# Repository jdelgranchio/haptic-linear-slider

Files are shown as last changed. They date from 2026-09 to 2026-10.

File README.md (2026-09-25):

# Haptic Linear Slider

A PCB for a motorized, haptic linear slider. An RP2354 (RP2350 with built-in flash) drives a
Bourns PSM01 motorized slide potentiometer through a DRV8876 H-bridge. The board also has a
14 V boost (TLV61048) for the motor supply, a buck converter (DIO54335), USB-C, and SWD over
Tag-Connect TC2030.

Made with **KiCad 10**.

## Layout

```
haptic-linear-slider.kicad_{pro,sch,pcb}
sym-lib-table, fp-lib-table       project library tables (paths use ${KIPRJMOD})
lib/
  _symbols/
    haptic-linear-slider.kicad_sym   project symbols, library nickname "_Symbols"
    MCU_RaspberryPi_RP2350.kicad_sym RP2350 symbol from Raspberry Pi's minimal design
  _footprints.pretty/                project footprints, library nickname "_Footprints"
  _3D/                               STEP models for project footprints
scripts/export.sh                    generates fab outputs and docs with kicad-cli
scripts/site.sh                      builds the GitHub Pages index from those outputs
.github/workflows/kicad.yml          CI: export, Pages (main), releases (v* tags)
```

Use the stock KiCad libraries for anything they already cover. Add a part to the project
libraries only when they don't have it.

## Adding a part from Mouser

1. Download the KiCad model from the Mouser product page (SamacSys / Library Loader).
2. In the Symbol Editor, copy the symbol into `_Symbols`. Rename it to
   `<short description> (<manufacturer>)`, e.g. `37V 3.5A H-Bridge (Texas Instruments)`.
3. Copy the `.kicad_mod` into `lib/_footprints.pretty/` and the `.stp` into `lib/_3D/`.
4. Set the footprint's 3D model to `${KIPRJMOD}/lib/_3D/<part>.stp`. Set the symbol's
   `Footprint` field to `_Footprints:<name>`.
5. Keep the `Manufacturer_Name`, `Manufacturer_Part_Number`, `Mouser Part Number` and
   `Mouser Price/Stock` fields. The BOM export reads them.

## Generating outputs

```sh
scripts/export.sh                 # writes everything to output/ (git-ignored)
STRICT_ERC=1 scripts/export.sh    # fail on ERC violations (STRICT_DRC=1, or STRICT=1 for both)
IBOM=path/to/generate_interactive_bom.py scripts/export.sh   # also build the interactive BOM
```

This produces:

- **checks**: ERC/DRC reports
- **fab**: Gerbers and drill files (plus a zip), a grouped BOM with part-number columns, a
  pick-and-place CSV
- **docs**: schematic PDF, PCB layers PDF, top/bottom assembly drawing PDFs, top/bottom 3D
  renders (PNG), a 3D STEP model
- **presentation**: board outline SVGs, bare and with part bodies, for slides and handbooks
- **datasheets**: a PDF per BOM part, from the `Datasheet` field. Some hosts (Mouser,
  Samsung, ST, …) block scripted downloads. Save those by hand as
  `lib/datasheets/<MPN>.pdf`; the CI run summary lists which ones are missing.

The Gerber layers come from the plot settings saved in the board file (PCB Editor → Plot).
Title blocks show `${REVISION}`: "dev" in the editor, the git tag or short SHA in exports.

## CI

- **Push to `main`**: builds everything, fails on ERC violations, and publishes the latest
  outputs to GitHub Pages. Only the newest deploy is kept. Per-commit workflow artifacts
  expire after 14 days.
- **Push a `v*` tag** (e.g. `v0.1`): also attaches all outputs to a GitHub release. Tag each
  revision you send to fab.

CI uses the `kicad/kicad:10.0-full` image (it includes the stock 3D models). DRC is report-only for now. Set `STRICT_DRC: 1` in the workflow once routing is done.

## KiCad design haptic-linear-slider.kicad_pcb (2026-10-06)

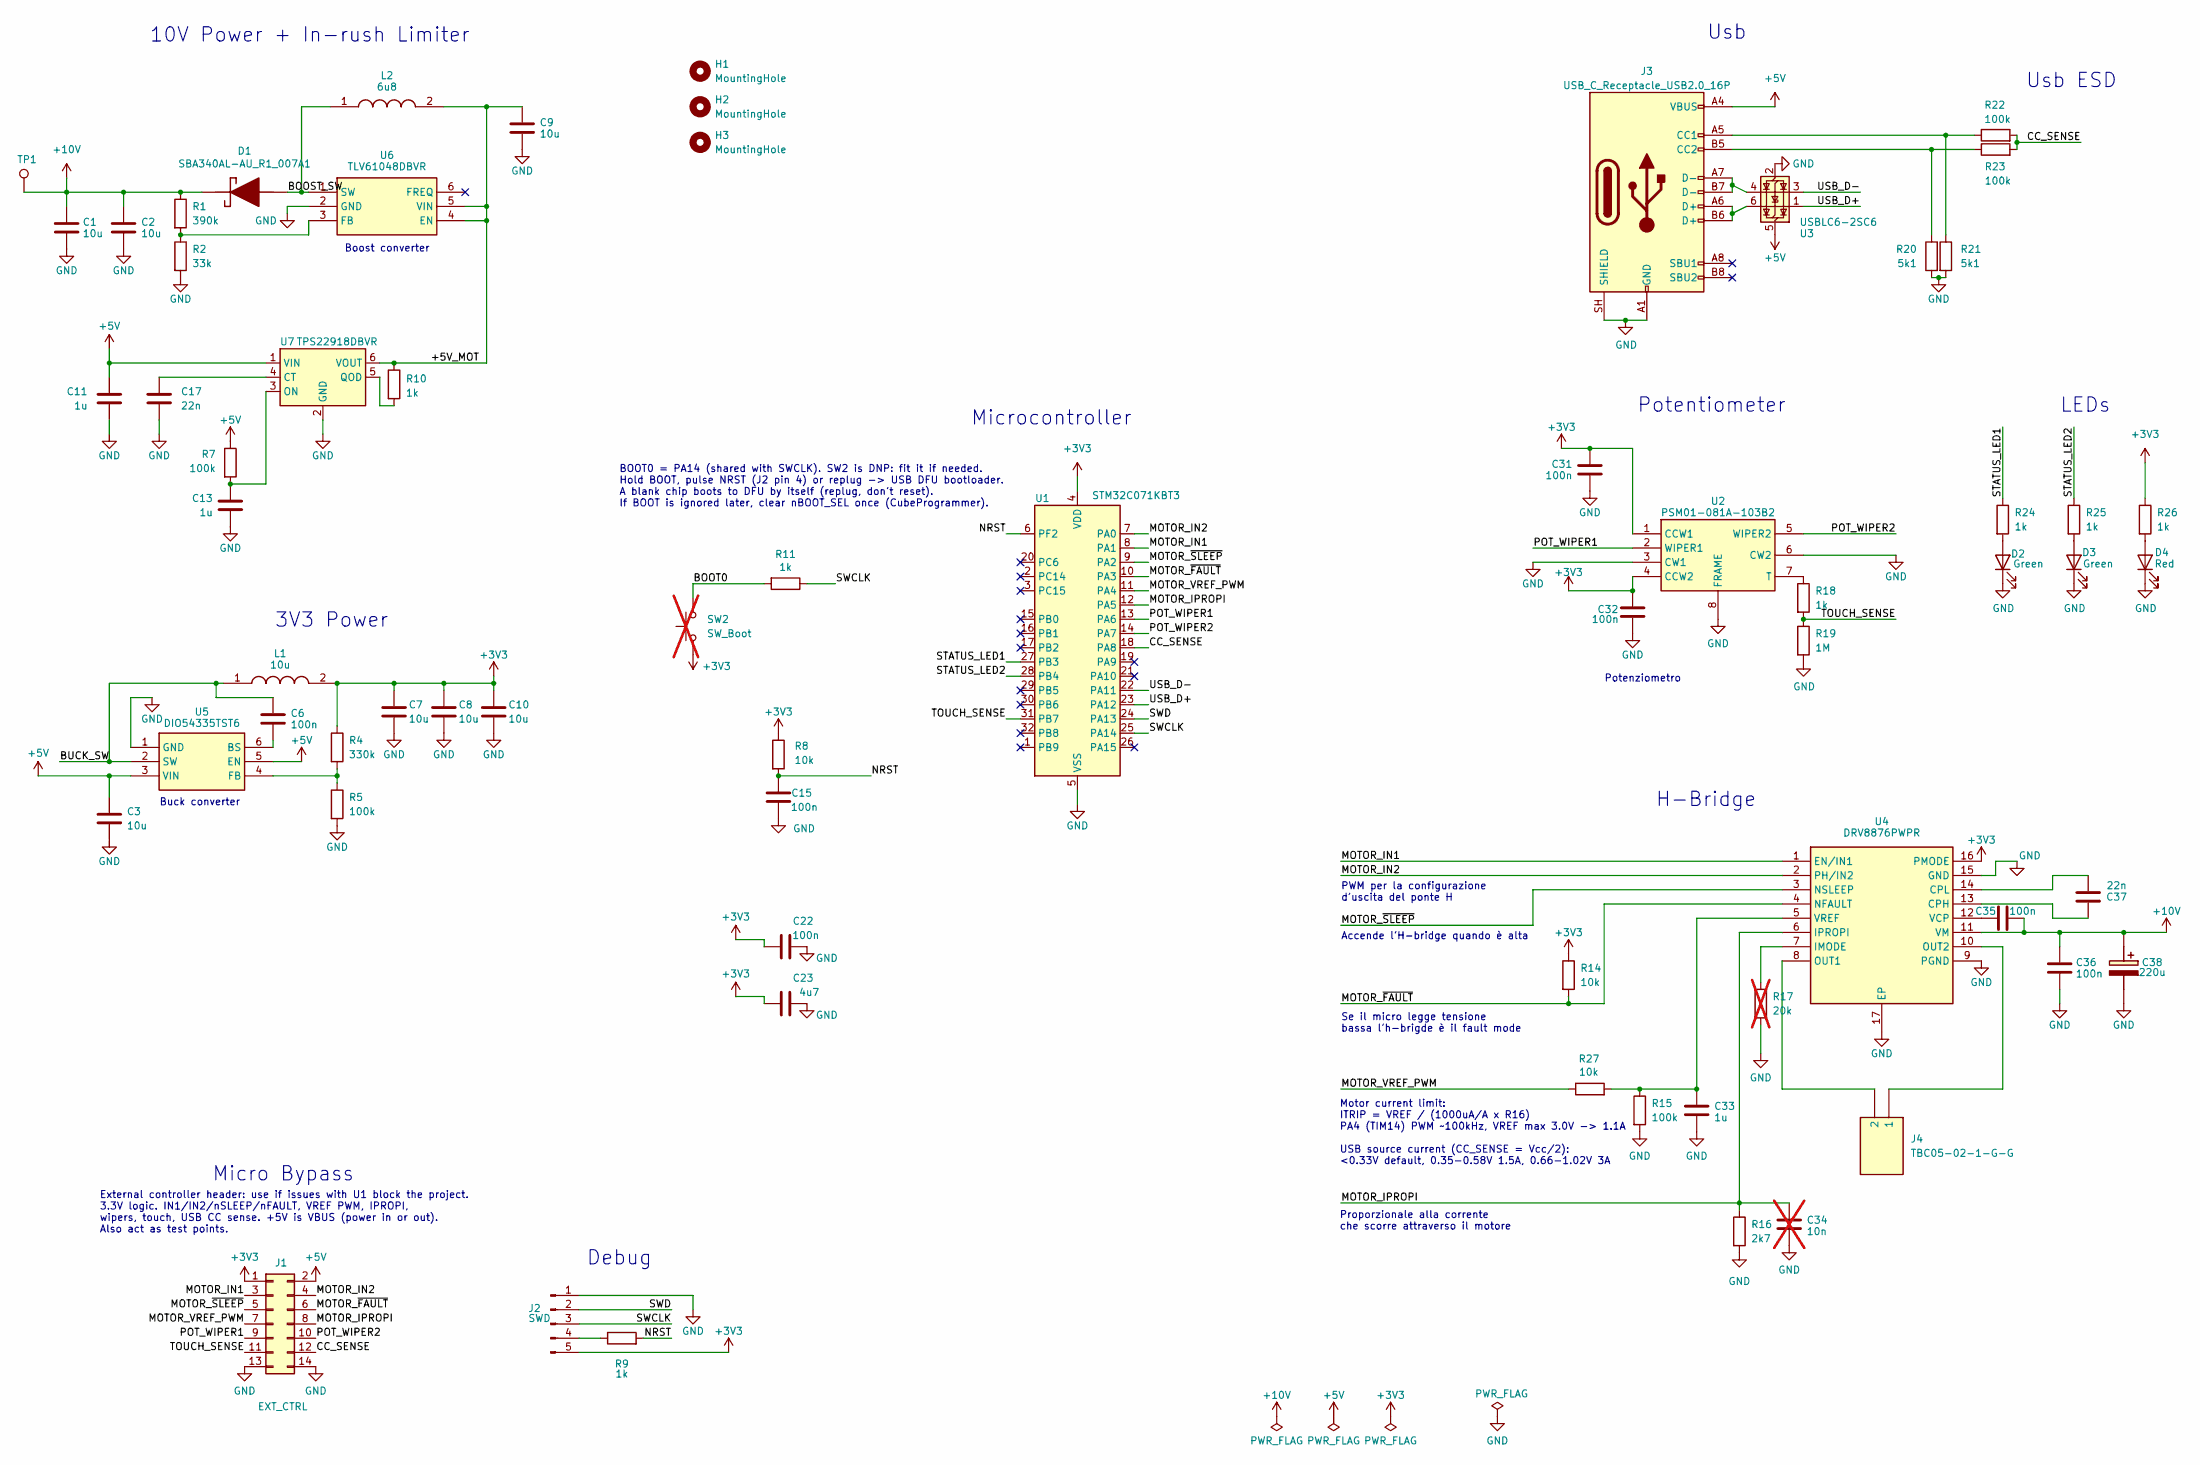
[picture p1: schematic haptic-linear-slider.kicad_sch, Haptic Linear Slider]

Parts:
C1, C2, C3, C7, C8, C9, C10: 10u; C_1210_3225Metric_Pad1.33x2.70mm_HandSolder; Manufacturer_Part_Number CL32B106KBJNNWE; Mouser Part Number 187-CL32B106KBJNNWE
C6, C15, C22, C31, C32, C35, C36: 100n; C_0805_2012Metric_Pad1.18x1.45mm_HandSolder; Mouser Part Number 187-CL21B104KBCNNNC
C11, C13: 1u; C_0805_2012Metric_Pad1.18x1.45mm_HandSolder; Mouser Part Number 187-CL21B105KBFNNNG
C17, C37: 22n; C_0805_2012Metric_Pad1.18x1.45mm_HandSolder; Mouser Part Number 187-CL21B223KBANNNC
C23: 4u7; C_0805_2012Metric_Pad1.18x1.45mm_HandSolder; Mouser Part Number 187-CL21A475KAQNNNE
C33: 1u; C_0805_2012Metric_Pad1.18x1.45mm_HandSolder; Manufacturer_Part_Number CL21B105KBFNNNG; Mouser Part Number 187-CL21B105KBFNNNG
C34: 10n; C_0805_2012Metric_Pad1.18x1.45mm_HandSolder; Manufacturer_Part_Number CL21B103KBANNNC; Mouser Part Number 187-CL21B103KBANNNC; not fitted
C38: 220u; CAPPRD350W52D800H1300; Manufacturer_Part_Number 860020574012; Mouser Part Number 710-860020574012
D1: SBA340AL-AU_R1_007A1; SODFL3618X110N; Mouser Part Number 241-SBA340AL-AUR17A1
D2, D3: Green; LED_0805_2012Metric_Pad1.15x1.40mm_HandSolder; Manufacturer_Part_Number 150080VS75000; Mouser Part Number 710-150080VS75000
D4: Red; LED_0805_2012Metric_Pad1.15x1.40mm_HandSolder; Manufacturer_Part_Number 150080RS75000; Mouser Part Number 710-150080RS75000
H1, H2, H3: MountingHole; MountingHole_3.2mm_M3
J1: EXT_CTRL; PinHeader_2x07_P2.54mm_Vertical; Manufacturer_Part_Number 61301421121; Mouser Part Number 710-61301421121
J2: SWD; PinHeader_1x05_P2.54mm_Vertical; Manufacturer_Part_Number 61300511121; Mouser Part Number 710-61300511121
J3: USB_C_Receptacle_USB2.0_16P; USB_C_Receptacle_GCT_USB4105-xx-A_16P_TopMnt_Horizontal; Manufacturer_Part_Number USB4105-GF-A; Mouser Part Number 640-USB4105-GF-A
J4: TBC05-02-1-G-G; TBC05021GG; Mouser Part Number 640-TBC05-02-1-G-G
L1: 10u; AMRM00101040100MA1; Mouser Part Number 673-AMRM101040100MA1
L2: 6u8; MPLSE60406R8; Mouser Part Number 946-MPL-SE6040-6R8
R1: 390k; R_0805_2012Metric_Pad1.20x1.40mm_HandSolder; Manufacturer_Part_Number RC0805FR-07390KL; Mouser Part Number 603-RC0805FR-07390KL
R2: 33k; R_0805_2012Metric_Pad1.20x1.40mm_HandSolder; Manufacturer_Part_Number RC0805FR-0733KL; Mouser Part Number 603-RC0805FR-0733KL
R4: 330k; R_0805_2012Metric_Pad1.20x1.40mm_HandSolder; Manufacturer_Part_Number RC0805FR-07330KL; Mouser Part Number 603-RC0805FR-07330KL
R5, R7, R15, R22, R23: 100k; R_0805_2012Metric_Pad1.20x1.40mm_HandSolder; Manufacturer_Part_Number RC0805FR-07100KL; Mouser Part Number 603-RC0805FR-07100KL
R8, R14, R27: 10k; R_0805_2012Metric_Pad1.20x1.40mm_HandSolder; Manufacturer_Part_Number RC0805FR-0710KL; Mouser Part Number 603-RC0805FR-0710KL
R9, R10, R11, R18, R24, R25, R26: 1k; R_0805_2012Metric_Pad1.20x1.40mm_HandSolder; Manufacturer_Part_Number RC0805FR-071KL; Mouser Part Number 603-RC0805FR-071KL
R16: 2k7; R_0805_2012Metric_Pad1.20x1.40mm_HandSolder; Manufacturer_Part_Number RC0805FR-072K7L; Mouser Part Number 603-RC0805FR-072K7L
R17: 20k; R_0805_2012Metric_Pad1.20x1.40mm_HandSolder; Manufacturer_Part_Number RC0805FR-0720KL; Mouser Part Number 603-RC0805FR-0720KL; not fitted
R19: 1M; R_0805_2012Metric_Pad1.20x1.40mm_HandSolder; Manufacturer_Part_Number RC0805FR-071ML; Mouser Part Number 603-RC0805FR-071ML
R20, R21: 5k1; R_0805_2012Metric_Pad1.20x1.40mm_HandSolder; Manufacturer_Part_Number RC0805FR-075K1L; Mouser Part Number 603-RC0805FR-075K1L
SW2: SW_Boot; 434133025816; Manufacturer_Part_Number 434133025816; Mouser Part Number 710-434133025816; not fitted
TP1: TestPoint; TestPoint_THTPad_D1.0mm_Drill0.5mm
U1: STM32C071KBT3; LQFP-32_7x7mm_P0.8mm; Manufacturer_Part_Number STM32C071KBT3; Mouser Part Number 511-STM32C071KBT3
U2: PSM01-081A-103B2; PSM01081A103B2; Mouser Part Number 652-PSM01081A103B2
U3: USBLC6-2SC6; Manufacturer_Part_Number USBLC6-2SC6; Mouser Part Number 511-USBLC6-2SC6
U4: DRV8876PWPR; SOP65P640X120-17N; Mouser Part Number 595-DRV8876PWPR
U5: DIO54335TST6; SOT95P280X90-6N; Mouser Part Number 453-DIO54335TST6
U6: TLV61048DBVR; SOT95P280X145-6N; Mouser Part Number 595-TLV61048DBVR
U7: TPS22918DBVR; SOT-23-6; Manufacturer_Part_Number TPS22918DBVR; Mouser Part Number 595-TPS22918DBVR

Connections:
+3V3: C7.1, C8.1, C10.1, C22.1, C23.1, C31.1, C32.1, J1.1, J2.5, L1.2, R4.1, R8.1, R14.1, R26.1, SW2.1, U1.4 (VDD), U2.1 (CCW1), U2.4 (CCW2), U4.16 (PMODE)
+5V: C3.1, C11.1, J1.2, J3.A4 (VBUS), J3.A9 (VBUS), J3.B4 (VBUS), J3.B9 (VBUS), R7.1, U3.5 (VBUS), U5.3 (VIN), U5.5 (EN), U7.1 (VIN)
+10V: C1.1, C2.1, C35.2, C36.1, C38.1 (+), D1.1 (K), R1.1, TP1.1 (1_1), U4.11 (VM)
/+5V_MOT: C9.1, L2.2, R10.1, U6.4 (EN), U6.5 (VIN), U7.6 (VOUT)
/BOOST_SW: D1.2 (A), L2.1, U6.1 (SW)
/BOOT0: R11.2, SW2.2
/BUCK_SW: C6.1, L1.1, U5.2 (SW)
/CC_SENSE: J1.12, R22.2, R23.2, U1.18 (PA8)
/MOTOR_IN1: J1.3, U1.8 (PA1), U4.1 (EN/IN1)
/MOTOR_IN2: J1.4, U1.7 (PA0), U4.2 (PH/IN2)
/MOTOR_IPROPI: C34.1, J1.8, R16.1, U1.12 (PA5), U4.6 (IPROPI)
/MOTOR_VREF_PWM: J1.7, R27.1, U1.11 (PA4)
/MOTOR_~FAULT: J1.6, R14.2, U1.10 (PA3), U4.4 (NFAULT)
/MOTOR_~SLEEP: J1.5, U1.9 (PA2), U4.3 (NSLEEP)
/NRST: C15.2, R8.2, R9.2, U1.6 (PF2)
/POT_WIPER1: J1.9, U1.13 (PA6), U2.2 (WIPER1)
/POT_WIPER2: J1.10, U1.14 (PA7), U2.5 (WIPER2)
/STATUS_LED1: R24.1, U1.27 (PB3)
/STATUS_LED2: R25.1, U1.28 (PB4)
/SWCLK: J2.3, R11.1, U1.25 (PA14)
/SWD: J2.2, U1.24 (PA13)
/TOUCH_SENSE: J1.11, R18.2, R19.1, U1.31 (PB7)
/USB_D+: U1.23 (PA12), U3.1 (I/O1)
/USB_D-: U1.22 (PA11), U3.3 (I/O2)
GND: C1.2, C2.2, C3.2, C7.2, C8.2, C9.2, C10.2, C11.2, C13.2, C15.1, C17.2, C22.2, C23.2, C31.2, C32.2, C33.2, C34.2, C36.2, C38.2 (-), D2.1 (K), D3.1 (K), D4.1 (K), J1.13, J1.14, J2.1, J3.A1 (GND), J3.A12 (GND), J3.B1 (GND), J3.B12 (GND), J3.SH (SHIELD), R2.2, R5.2, R15.2, R16.2, R17.2, R19.2, R20.2, R21.2, U1.5 (VSS), U2.3 (CW1), U2.6 (CW2), U2.8 (FRAME), U2.9 (FRAME), U3.2 (GND), U4.9 (PGND), U4.15 (GND), U4.17 (EP), U5.1 (GND), U6.2 (GND), U7.2 (GND)
unnamed: D2.2 (A), R24.2
unnamed: D3.2 (A), R25.2
unnamed: D4.2 (A), R26.2
unnamed: J2.4, R9.1
unnamed: J3.A5 (CC1), R21.1, R22.1
unnamed: J3.B5 (CC2), R20.1, R23.1
unnamed: J3.A6 (D+), J3.B6 (D+), U3.6 (I/O1)
unnamed: J3.A7 (D-), J3.B7 (D-), U3.4 (I/O2)
unnamed: R18.1, U2.7 (T)
unnamed: C37.1, U4.13 (CPH)
unnamed: C37.2, U4.14 (CPL)
unnamed: R17.1, U4.7 (IMODE)
unnamed: J4.2, U4.8 (OUT1)
unnamed: J4.1, U4.10 (OUT2)
unnamed: C35.1, U4.12 (VCP)
unnamed: C33.1, R15.1, R27.2, U4.5 (VREF)
unnamed: C6.2, U5.6 (BS)
unnamed: R4.2, R5.1, U5.4 (FB)
unnamed: R1.2, R2.1, U6.3 (FB)
unnamed: C17.1, U7.4 (CT)
unnamed: C13.1, R7.2, U7.3 (ON)
unnamed: R10.2, U7.5 (QOD)

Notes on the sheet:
Micro Bypass
Proporzionale alla corrente che scorre attraverso il motore
Usb ESD
Potenziometro
Se il micro legge tensione bassa l'h-brigde è il fault mode
Boost converter
H-Bridge
BOOT0 = PA14 (shared with SWCLK). SW2 is DNP: fit it if needed. Hold BOOT, pulse NRST (J2 pin 4) or replug -> USB DFU bootloader. A blank chip boots to DFU by itself (replug, don't reset). If BOOT is ignored later, clear nBOOT_SEL once (CubeProgrammer).
Usb
Motor current limit: ITRIP = VREF / (1000uA/A x R16) PA4 (TIM14) PWM ~100kHz, VREF max 3.0V -> 1.1A USB source current (CC_SENSE = Vcc/2): <0.33V default, 0.35-0.58V 1.5A, 0.66-1.02V 3A
10V Power + In-rush Limiter
Buck converter
Accende l'H-bridge quando è alta
3V3 Power
Microcontroller
External controller header: use if issues with U1 block the project. 3.3V logic. IN1/IN2/nSLEEP/nFAULT, VREF PWM, IPROPI, wipers, touch, USB CC sense. +5V is VBUS (power in or out). Also act as test points.
Debug
Potentiometer
PWM per la configurazione d'uscita del ponte H
LEDs

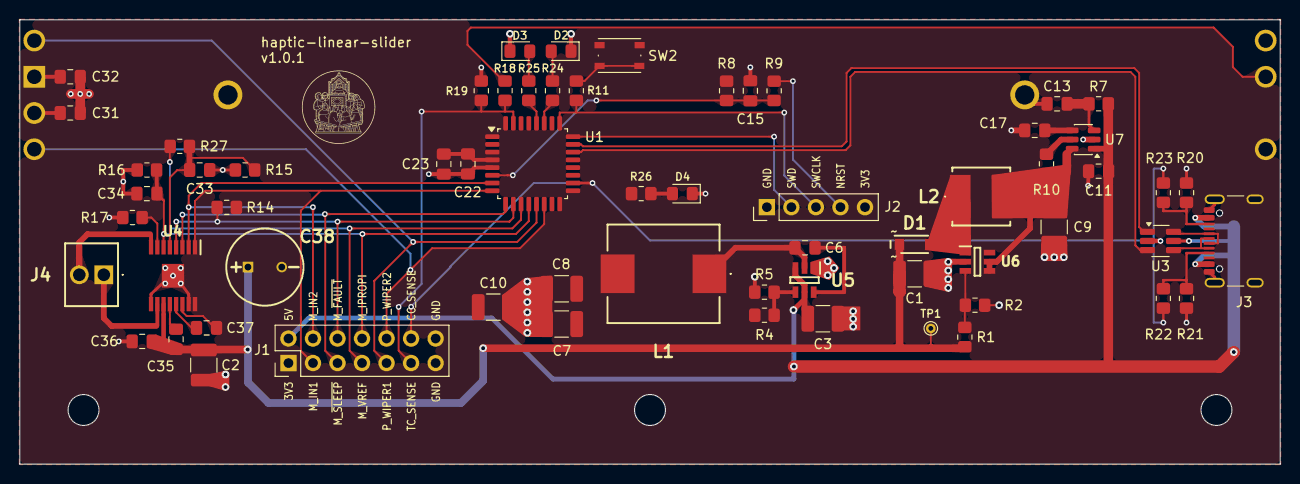
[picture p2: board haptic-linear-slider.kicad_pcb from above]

Board: 2 copper layers, 130.5 x 46.0 mm, 67 parts (1 on the bottom side), 47 nets.

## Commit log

2026-04-24 cleaned up footprints
2026-04-24 3D models are mostly working
    [haptic-linear-slider.kicad_pcb, haptic-linear-slider.kicad_sch]
2026-04-25 testo spostato
    [haptic-linear-slider.kicad_sch]
2026-09-25 feat: symbols and cleaning, ESD
    [haptic-linear-slider.kicad_pcb, haptic-linear-slider.kicad_sch]
2026-09-25 Moved pin on micro for better routing
    [haptic-linear-slider.kicad_pcb, haptic-linear-slider.kicad_sch]
2026-09-27 Ho fatto il layout di USB, convertitori DCDC e ponte H. Il layout della USB non so come si faccia e l'ho fatto a caso. Ho cambiato il piano superiore da GND a 3V3. Buonanotte Gengis.
    [haptic-linear-slider.kicad_pcb, haptic-linear-slider.kicad_sch]
2026-10-01 nuovo micro e altro IC che si saldano meglio, routing rifatto ma va ancora rivisto
    [haptic-linear-slider.kicad_pcb, haptic-linear-slider.kicad_sch]
2026-10-01 spostato J2
    [haptic-linear-slider.kicad_pcb]
2026-10-01 piccole cose
    [haptic-linear-slider.kicad_pcb, haptic-linear-slider.kicad_sch]
2026-10-05 review of main components
    [haptic-linear-slider.kicad_pcb, haptic-linear-slider.kicad_sch]
2026-10-06 ready to order
    [haptic-linear-slider.kicad_pcb, haptic-linear-slider.kicad_sch]
